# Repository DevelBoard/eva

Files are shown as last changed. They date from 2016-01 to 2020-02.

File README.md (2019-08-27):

# Develer EVA01 Project
Schematics and Gerber for DevelBoard Evaluation, and shield boards.

## EVA01 Releases

### EVA01 Rev.3 (eva01-R3)
 * PCB release Rev.C (pcb-eva01-Rev-C)
 * Move WLAN_PWR singal form PB29 to PE5 pin.
 * Silk screen cosmetic fixes
 
### EVA01 Rev.2 (eva01-R2)
 * PCB release Rev.B (pcb-eva01-Rev-B)
 * Minor fixes
 * Change USB Host connector position
 * Reduce backup battery size
 * Add Bridge diode on Power supply connector
 * Cosmetic fixes
 * Issues:
   * WiFi/BlueTooth enable: Put R10 to NP and R11 to 22R.

### EVA01 Rev.1 (eva01-R1)
 * First Release
 * PCB release Rev.A (pcb-eva01-Rev-A)
 * Issues:
   * J3 Connector Wrong Power Jack polarity -> Inside pin is GND, and output is +24V
 
## Shield Board Releases

### SHIELD Display 7'', CAN, RS232, RS485 Rev.0 (shield_can-display-R0)
* First Release: Automotive shield version. This shield provvide CAN, RS485 and RS232 peripherals, and LCD Display 7'' 800x480 with integrated resisteve touch. The board support the external capacitive touch frame.
 * PCB release Rev.A (pcb-shield_can-display-Rev-A)
 * Issues:
   * J9 Connector mirrored -> the capacitive touch frame not work.
   * Missing pull down on lcd backlight enable

### SHIELD Display 4.3'' Rev.1 (shield_display_4.3-R1)
* First Release: Display shield version. The shield support LCD Display 4.3'' 480x272  with integrated resisteve touch.
 * PCB release Rev.A (pcb-shield_display_4.3-Rev-A)
 * Issues:
   * Missing pull down on lcd backlight enable

### SHIELD IO Rev.0 (shield_io-R0)
 * First release: Generic IO shield this shield provvide 4 Relay SPDT, 2 Digital input Optocoupled, 2 Digital Input, 4 ADC input, 2 ADC Current shunt, 2 Voltage DAC and 2 Current DAC.

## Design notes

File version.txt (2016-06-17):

[eva01]
name=EVA01 Evaluation board for DevelBoard
hw_ver=3
pcb_ver=C
date=20160415

[shield_display_4.3]
name=EVA01 Shield Display 4.3''
hw_ver=2
pcb_ver=C
date=20160616

[shield_can-display]
name=EVA01 Shield Display 7'' with CAN, RS232, RS485
hw_ver=2
pcb_ver=B
date=20160616

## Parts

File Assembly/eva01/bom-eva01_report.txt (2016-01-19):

#     #                             ######
##   ## ###### #####   ####  ###### #     #  ####  #    #
# # # # #      #    # #    # #      #     # #    # ##  ##
#  #  # #####  #    # #      #####  ######  #    # # ## #
#     # #      #####  #  ### #      #     # #    # #    #
#     # #      #   #  #    # #      #     # #    # #    #
#     # ###### #    #  ####  ###### ######   ####  #    #

Report file.
Date: Tue 19 January 2016 10:26:56
Directory: Assembly/eva01
Project Name: EVA01 Evaluation board for DevelBoard
Hardware Revision: 2
PCB Revision: B

Assembly/eva01/bom-eva01.xls
SRC file: Assembly/eva01\tmp_bom-eva01.xls
OUT file: Assembly/eva01\bom-eva01.xls

Check Merged items:
--------------------------------------------------------------------------------
>>  Assembly/eva01\tmp_bom-eva01.xls
>>  Merged key: Mini USB SMT Type B 5 Contacts (WE 65100516121)usb_typeB_mini_smd (Connector)
>>  Merged key: Pin Header, 2pin, 1x2, 2.54mm, THDHEADER_1X2_2.54MM_THD (Connector)
>>  Merged key: CR1612/1616/1620/1632 (3013, Keystone)Battery_holder_16mm_thd (Connector)
>>  Merged key: Pin header 26x2 Stacked > 16mmHEADER_2x26_2.54MM_THD (Connector)
>>  Merged key: Pin header 26x2 Stacked > 16mmHEADER_2x26_2.54MM_THD (Connector)
>>  Merged key: Terminal block Header 3.5mm Horizontal (WE 691322110002)TBLOCK_1X2_3.5MM_HOR_THD (Connector)
>>  Merged key: WR-DC_DC Power Jack_Right Angled_THT (WE  694108301002)DC_Jack_6.5x2.5mm_right_tht (Connector)
!!  Not Populate connector, leave unmerged..[NP (ANT_WLAN_2)] [J15] match[u'NP']
>>  Merged key: SMA, Jack, Right angle, PCB socket, 50ohm (TE 5-1814400-1) NP  (ANT_WLAN_2)SMA_Jack_Female_5.08mm_THD ( NP  (ANT_WLAN_2))
>>  Merged key: WR-CRD Micro SD_Push and Push (693071010811)micro_sd_holder_pp (Connector)
>>  Merged key: Pin header 26x2 Stacked > 16mmHEADER_2x26_2.54MM_THD (Connector)
>>  Merged key: SMA, Jack, Right angle, PCB socket, 50ohm (TE 5-1814400-1)SMA_Jack_Female_5.08mm_THD (Connector)
>>  Merged key: USB Type-A Double Connector (WE  61400826021)USB_TypeA_Double_THD (Connector)
>>  Merged key: Integrated RJ45 Transformer WE-RJ45LAN (WE 74990111217)RJ45_lan_transformer_horizontal (Connector)
>>  Merged key: Pin Header, 4pin, 2x2, 2.54mm, THDHEADER_2X2_2.54MM_THD (Connector)
>>  Merged key: LED Green0603_[1608]_LED (+1.8V)
>>  Merged key: LED Green0603_[1608]_LED (Vusb)
>>  Merged key: LED Green0603_[1608]_LED (+5V)
>>  Merged key: LED Green0603_[1608]_LED (+3.3V)
>>  Merged key: LED Green0603_[1608]_LED (+24V)

================================================================================
 File num: 1

-  C  Capacitors
       C    52
-  D  Diodes
       D     9
-  J  Connectors
       J    14
-  L  Inductors, chokes
       L    21
-  Q  Transistors
       Q     1
-  S  Mechanical parts and buttons
       S     1
-  R  Resistors
       R    75
-  DZ Zener, Schottky, Transil
      DZ     1
-  U  IC
       U    13

~~~~~~~~~~~~~~~~~~~~~~~~~~~~~~~~~~~~~~~~~~~~~~~~~~~~~~~~~~~~~~~~~~~~~~~~~~~~~~~~
>>  Total: 187

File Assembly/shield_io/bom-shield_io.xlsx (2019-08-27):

Bill of Materials
Date: 27/08/2019
Project: Input/Output and Analog expation shield for DevelBoard PN: -
Hardware_version: 0
PCB_version: A
BOM files:
- bom-shield_io.csv
Statistics
NP=NOT POPULATE (NON MONTARE)!
T.Qty | bom-shield_io.csv | Designator | Comment | Footprint | Description
J * Connectors and holders *
4 | 4 | J7, J8, J9, J10 | Connector | TBLOCK_1X2_3.5MM_HOR_THD | Terminal block Header 3.5mm Horizontal (WE 691322110002)
3 | 3 | J12, J13, J14 | Connector | SOCKET_2x26_2.54MM_THD | Socket Header, 52 pin, 26x2, 2.54mm, H=8.5mm
9 | 9 | J1, J2, J3, J4, J5, J6, J11, J15, J16 | Connector | TBLOCK_1X3_3.5MM_HOR_THD | Terminal block Header 3.5mm Horizonta
R * Resistor components *
29 | 29 | R3, R4, R5, R9, R16, R22, R26, R29, R34, R37, R67, R69, R78, R79, R82, R83, R84, R88, R92, R93, R98, R99, R100, R101, R102, R104, R106, R107, R386 | NP | 0603_[1608] | Resistor
2 | 2 | R87, R90 | NP | 0805_[2012] | Resistor
19 | 19 | R1, R7, R8, R10, R14, R19, R25, R28, R33, R36, R57, R58, R85, R89, R94, R95, R103, R105, R387 | 0R | 0603_[1608] | Resistor
4 | 4 | R71, R74, R76, R77 | 22R | 0603_[1608] | Resistor
27 | 27 | R2, R6, R11, R13, R18, R24, R27, R32, R35, R41, R44, R45, R47, R48, R50, R51, R53, R54, R59, R60, R61, R62, R63, R64, R65, R96, R97 | 33R | 0603_[1608] | Resistor
4 | 4 | R30, R31, R38, R39 | 50R mOhm 1% | 1210_[3225] | Resistor
2 | 2 | R86, R91 | 100R 0.1% | 0805_[2012] | Resistor
2 | 2 | R80, R81 | 220R | TRIMMER_THD_5x10MM_HORIZONTAL | Trimmer 23 Turn 220ohm (T93YA221KT20;)
2 | 2 | R70, R75 | 220R | 0603_[1608] | Resistor
5 | 5 | R23, R66, R68, R72, R73 | 1k | 0603_[1608] | Resistor
1 | 1 | R21 | 8k2 1% | 0603_[1608] | Resistor
1 | 1 | R17 | 10k 1% | 0603_[1608] | Resistor
2 | 2 | R12, R15 | 10k | 0603_[1608] | Resistor
1 | 1 | R20 | 47k 1% | 0603_[1608] | Resistor
C * Capacitors *
10 | 10 | C20, C21, C23, C24, C25, C26, C27, C28, C29, C30 | NP | 0603_[1608] | Ceramic X7R 50V
18 | 18 | C2, C4, C5, C7, C8, C9, C11, C12, C13, C14, C15, C16, C17, C18, C19, C22, C31, C104 | 100nF | 0603_[1608] | Ceramic X7R 50V
1 | 1 | C6 | 1uF | 0603_[1608] | Ceramic X5R 25V
3 | 3 | C1, C32, C106 | 10uF | 1206_[3216] | Ceramic X7R 25V
2 | 2 | C3, C10 | 10uF | 0805_[2012] | Ceramic X5R 10V
D * Diodes, Zener, Schottky, LED, Transil *
2 | 2 | DZ1, DZ2 | BZX84-C2V7 | SOT-23 | Zener 2,7V
2 | 2 | D1, D2 | S2B | DO214AA_K1-A2_SMB | S2B Diode
L * L Inductors, chokes *
2 | 2 | L1, L2 | 10uH | 1210_[3225] | INDUCTOR, 1210 CASE, 10.0UH (ELJPA100KF)
Q * Q Transistors, MOSFET *
2 | 2 | Q1, Q2 | FCX690BTA | SOT-89 | NPN Bipolar Transistor
U * Integrates and chips *
1 | 1 | U5 | 24C128 | SOIC8 | EEPROM
1 | 1 | U12 | ACPL-827 | SOIC8_OPTO | Optocoupler
1 | 1 | U44 | AD5624RBRMZ | MSOP50P490X110-10P | 12bit DAC
1 | 1 | U1 | AD7998BRU | TSOP65P640X120-20L | ADC 12bit I2C
2 | 2 | U3, U4 | AD8418BRMZ | MSOP65P490X110-8P | 12bit DAC
2 | 2 | U11, U13 | LM317D | SOT-223 | 3-Terminal Adjustable Regulator, 3-pin SOT-223
1 | 1 | U14 | OPA4188AID | SOIC14 | Quad Op Amp
4 | 4 | U7, U8, U9, U10 | Relay, Rele' | relays_spco_thd_28x12mm_5mm | Rele NT75CS16DC12V0.415.0 16A 12V
1 | 1 | U2 | TLV431 SOT23 | SOT-23 | TLV431BQDBZT
1 | 1 | U6 | ULN2803 | SOIC18 | BJT Darlinton Array

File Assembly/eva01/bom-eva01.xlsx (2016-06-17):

Bill of Materials
Date: Friday, 17 June 2016 12:10:39
Project: EVA01 Evaluation board for DevelBoard
Hardware_version: 3
PCB_version: C
BOM files:
- bom-eva01.xlsx
NP=NON MONTARE!
Statistics:
52 | C Capacitors
9 | D Diodes
14 | J Connectors
21 | L Inductors, chokes
1 | Q Transistors
1 | S Mechanical parts and buttons
75 | R Resistors
1 | DZ Zener, Schottky, Transil
13 | U IC
187 | Total
T.Qty | bom-eva01.xlsx | Designator | Comment | Footprint | Description
J Connectors
1 | 1 | J10 | Connector | HEADER_2X2_2.54MM_THD | Pin Header, 4pin, 2x2, 2.54mm, THD
1 | 1 | J2 | Connector | TBLOCK_1X2_3.5MM_HOR_THD | Terminal block Header 3.5mm Horizontal (WE 691322110002)
3 | 3 | J1, J7, J16 | Connector | HEADER_2x26_2.54MM_THD | Pin header, 2x26, 2.54mm, Stacked H=10mm (LE210280-R)
1 | 1 | J12 | Connector | USB_TypeA_Double_THD | USB Type-A Double Connector (WE 61400826021)
1 | 1 | J4 | Connector | HEADER_1X2_2.54MM_THD | Pin Header, 2pin, 1x2, 2.54mm, THD
1 | 1 | J9 | Connector | usb_typeB_mini_smd | Mini USB SMT Type B 5 Contacts (WE 65100516121)
1 | 1 | J11 | Connector | micro_sd_holder_pp | WR-CRD Micro SD_Push and Push (693071010811)
1 | 1 | J6 | Connector | Battery_holder_16mm_thd | CR1612/1616/1620/1632 (3013, Keystone)
1 | 1 | J3 | Connector | DC_Jack_6.5x2.5mm_right_tht | WR-DC_DC Power Jack_Right Angled_THT (WE 694106301002)
1 | 1 | J14 | Connector | SMA_Jack_Female_5.08mm_THD | SMA, Jack, Right angle, PCB socket, 50ohm (TE 5-1814400-1)
1 | 1 | J13 | Connector | RJ45_lan_transformer_horizontal | Integrated RJ45 Transformer WE-RJ45LAN (WE 74990111217)
1 | 1 | J15 | NP Connector | SMA_Jack_Female_5.08mm_THD | SMA, Jack, Right angle, PCB socket, 50ohm (TE 5-1814400-1)
S Mechanical parts and buttons
1 | 1 | SW1 | RESET | TACTILE_SWITCH_6x6MM_SMD | Tactile switch smd H=4.3mm 10x6mm (like cod. Farnell 2435308)
R Resistors
15 | 15 | R1, R2, R3, R4, R5, R6, R7, R10, R63, R89, R90, R91, R92, R93, R94 | NP | 0603_[1608] | Resistor
1 | 1 | R35 | NP (10k) | 0603_[1608] | Resistor
1 | 1 | R36 | NP (1k) | 0603_[1608] | Resistor
1 | 1 | R87 | 0R | 0603_[1608] | Resistor
26 | 26 | R11, R33, R37, R38, R44, R45, R46, R47, R48, R49, R51, R52, R54, R57, R58, R59, R60, R62, R79, R80, R81, R82, R83, R84, R85, R86 | 22R | 0603_[1608] | Resistor
1 | 1 | R150 | 56R | 0603_[1608] | Resistor
1 | 1 | R17 | 180R | 0603_[1608] | Resistor
3 | 3 | R55, R56, R77 | 470R | 0603_[1608] | Resistor
2 | 2 | R8, R16 | 680R | 0603_[1608] | Resistor
13 | 13 | R9, R14, R15, R39, R50, R53, R70, R72, R73, R74, R75, R76, R78 | 10k | 0603_[1608] | Resistor
5 | 5 | R13, R40, R41, R42, R43 | 68k | 0603_[1608] | Resistor
6 | 6 | R65, R66, R67, R68, R69, R71 | 100k | 0603_[1608] | Resistor
C Capacitors
1 | 1 | C22 | NP (100nF) | 0603_[1608] | Ceramic X7R 50V
2 | 2 | C45, C46 | 100pF | 0603_[1608] | Ceramic COG 50V
2 | 2 | C9, C17 | 10nF | 0603_[1608] | Ceramic X7R 50V
30 | 30 | C2, C3, C6, C11, C14, C15, C18, C19, C20, C21, C23, C25, C27, C28, C30, C31, C32, C33, C34, C35, C36, C37, C38, C39, C43, C44, C47, C48, C73, C74 | 100nF | 0603_[1608] | Ceramic X7R 50V
3 | 3 | C8, C12, C42 | 1uF | 1206_[3216] | Ceramic X7R 50V
1 | 1 | C41 | 4.7uF | 0805_[2012] | Ceramic X7R 10V
1 | 1 | C16 | 4.7uF | 1206_[3216] | Ceramic X5R 25V
10 | 10 | C1, C7, C10, C13, C24, C26, C29, C40, C49, C50 | 10uF | 1206_[3216] | Ceramic X5R 25V
1 | 1 | C4 | 100uF | CAP_6x6_D8_SMD | EEEFK1H101P SMT 6x6 35V
1 | 1 | C5 | 100uF | [7343]_CAP_TAN | Tantalum 10V (T495D107K010ATE100)
D Diodes
1 | 1 | D1 | Bridge Diode | Diode_bridge_smd | MBS4 (Farnell cod:4084985)
5 | 5 | D3, D4, D5, D8, D17 | LED | 0603_[1608]_LED | LED Green
2 | 2 | D6, D7 | MBR120VLSFT1G | SOD-123 | Diode Schottky low Vf, If 1A (PMEG3010ER; MBRX120LF)
1 | 1 | D2 | SMBJ28A | DO214AA_12 | TRANSIL (SM6T12A)
DZ Zener, Schottky, Transil
1 | 1 | DZ1 | B340A | DO214AA_12 | Diode Schottky (STPS2L40U)
L Inductors, chokes
2 | 2 | L10, L11 | Line filter (WE 744232090) | WE-CNSW_1206 | Common mode line filter
1 | 1 | L19 | NP (220 ohm @ 100MHz) | 0805_[2012] | Ferrite Beat (WE 742792022)
1 | 1 | L4 | 10uH WE 74437334100 | WE-LHMI_5020 | SMD Shielded Tiny Power Inductor
3 | 3 | L14, L20, L21 | 180H @ 100Mhz | 0603_[1608] | Ferrite Beat (WE 7427927218)
14 | 14 | L1, L2, L3, L5, L6, L7, L8, L9, L12, L13, L15, L16, L17, L18 | 220H ohm @ 100MHz | 0805_[2012] | Ferrite Beat (WE 742792022)
Q Transistors
1 | 1 | Q1 | NP (IRLML6402) | SOT-23 | Mos N Channel
U IC
1 | 1 | U12 | 32.768kHz Oscillator | CRYSTAL_3.2X1.5MM_4P_SMD | 32.768kHz Oscillator (EPSON X1B0002110001 SG-3030CM)
1 | 1 | U1 | DevelBoard | develboard_footprint | Faster Little Linux Module
1 | 1 | U10 | FPF2124 | SOT-23-5 | Power Load Switch
1 | 1 | U4 | FT232RQ | QFN-32 | Serial TTL 232 <-> USB (QFN-32)
1 | 1 | U3 | LD29150DT33R | TO-252_D2PAK_LARGEPAD | Very Low Drop Linear regulator 3.3V (BA33BC0FP-E2; MIC2940A-3.3WU)
1 | 1 | U28 | LM1117-18 | SOT-223 | LDO, Fixed Vout = 1.8V
1 | 1 | U2 | LM22670MRE-5.0/NOPB | SOIC8_PAD | Power switch
1 | 1 | U5 | SP2526A-1EN-L | SOIC8 | USB Power Supply swtich HI-SIDE dual.
2 | 2 | U6, U7 | TVS Array (WE 82400152) | SOT-563 | TVS Array (WE 82400152)
1 | 1 | U8 | TXB0108PW | TSOP65P640X120-20L | 8-bit bidirectional level translator
1 | 1 | U11 | TXS0108E | TSOP65P640X120-20L | 8-bit bidirectional level translator
1 | 1 | U9 | WL1831MOD | WL18XX_E-13.4X13.3-N100_0.75 | Wifi & Bluethoot module

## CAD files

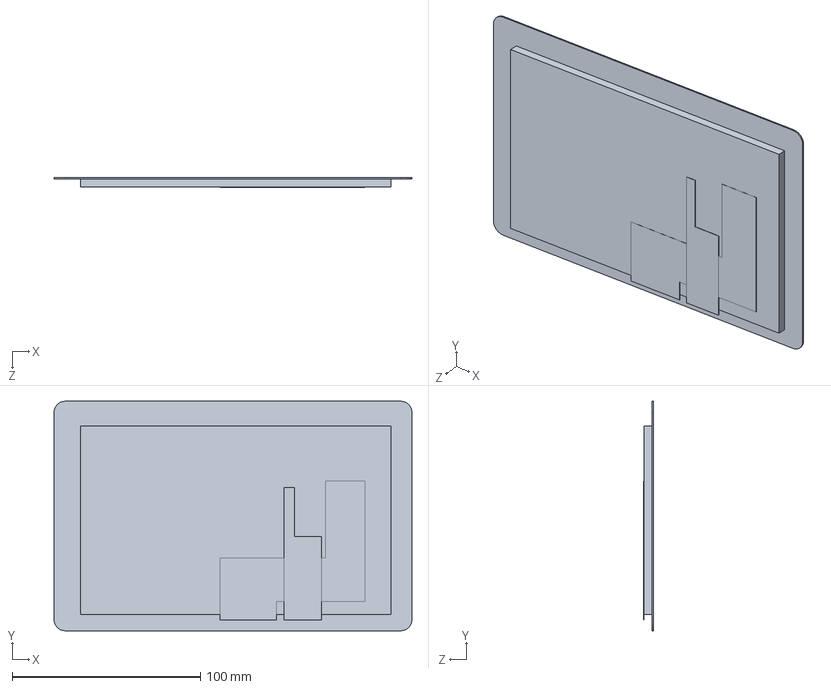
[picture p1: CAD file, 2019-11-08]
Drawing/shield_can-display/display_7.SLDPRT
190.1 x 121.9 x 5.38 mm

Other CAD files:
Drawing/eva01.DWG
Drawing/eva01_outline.dwg

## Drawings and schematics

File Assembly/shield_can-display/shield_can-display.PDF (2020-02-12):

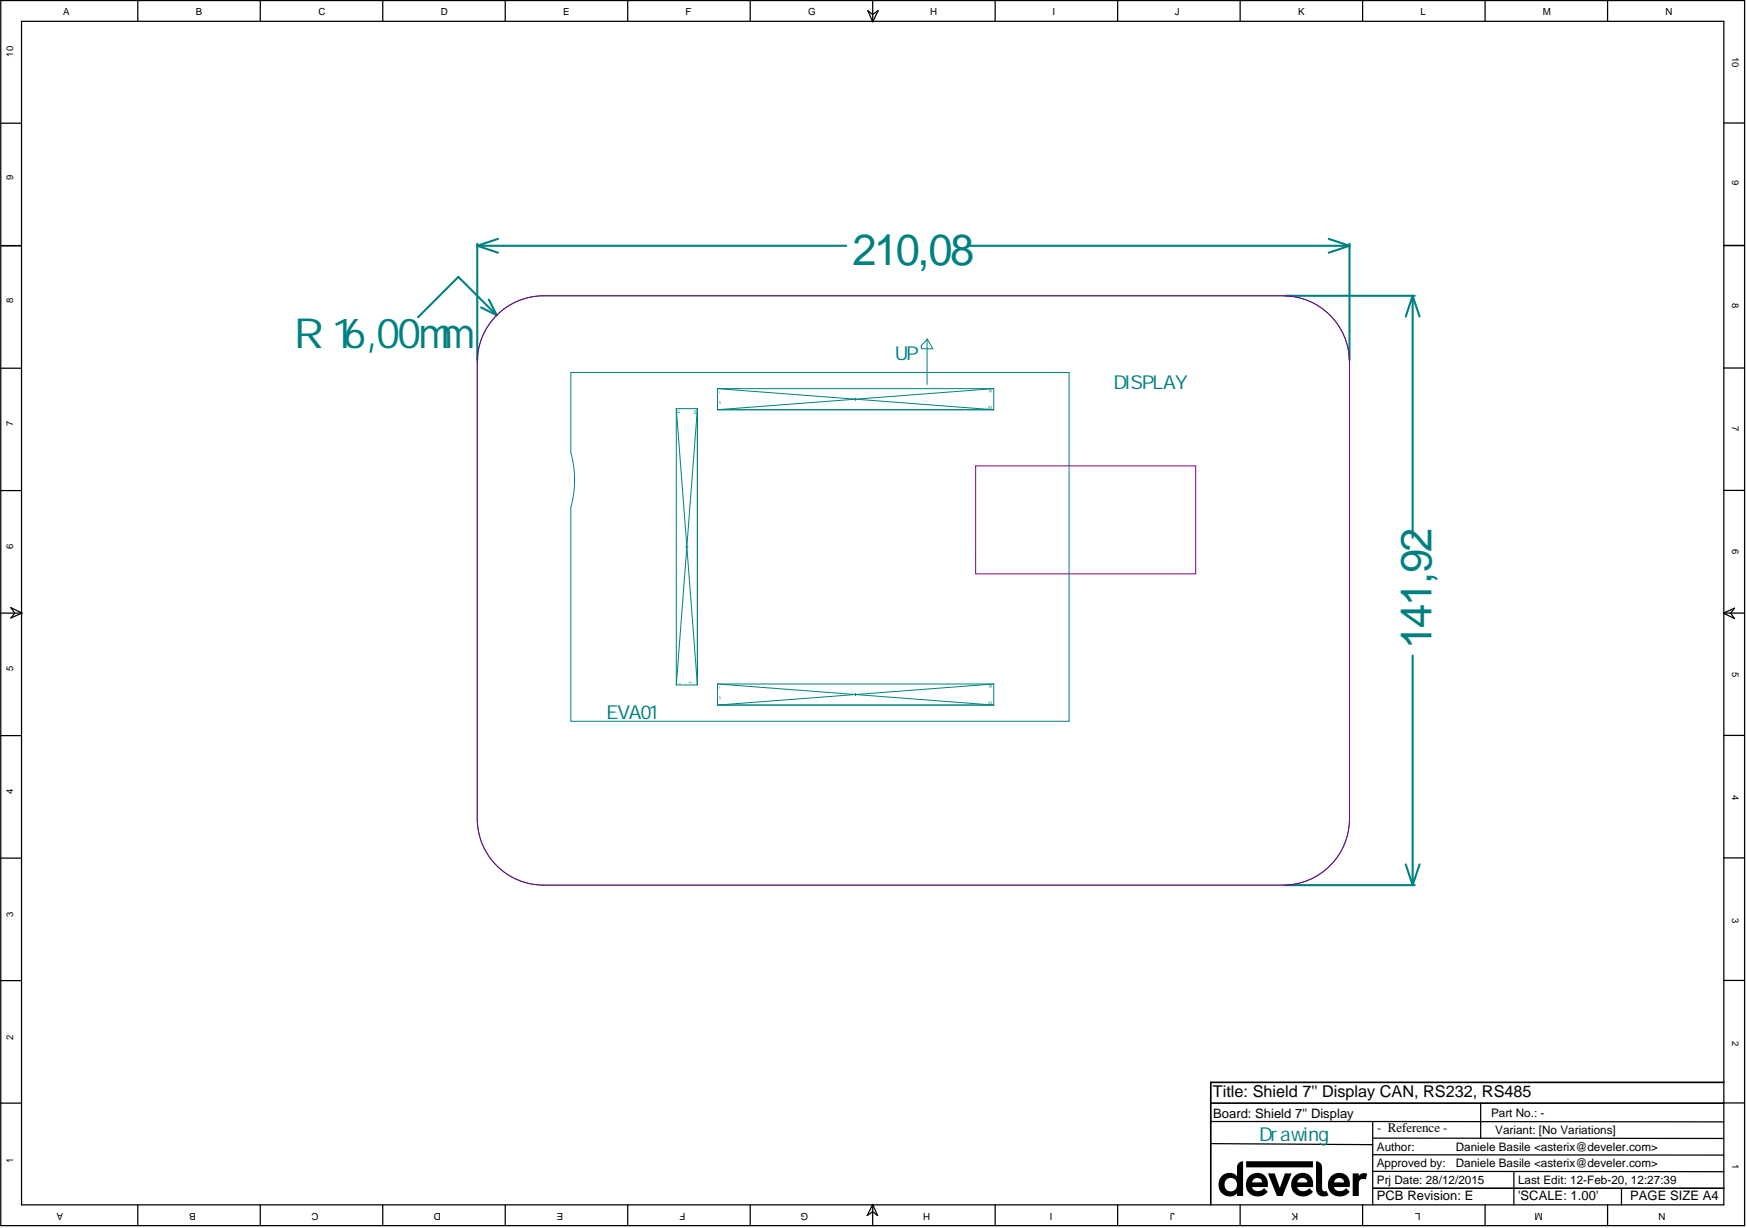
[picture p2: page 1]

Title: Shield 7'' Display CAN, RS232, RS485

Board: Shield 7'' Display | Part No.: -

Dr awing | - Reference - | Variant: [No Variations]

Daniele Basile <asterix@develer.com>

Prj Date: 28/12/2015 | Last Edit: 12-Feb-20, 12:27:39
PCB Revision: E | 'SCALE: 1.00' | PAGE SIZE A4

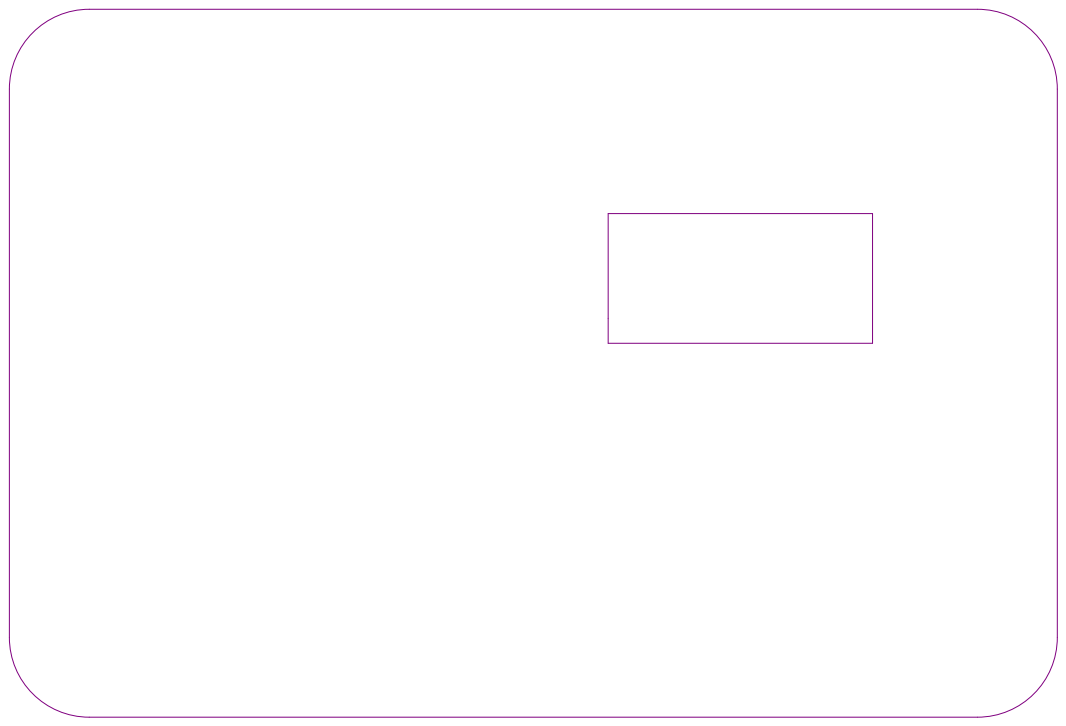
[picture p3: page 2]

Title: Shield 7'' Display CAN, RS232, RS485

Board: Shield 7'' Display | Part No.: -
Top Assembl y

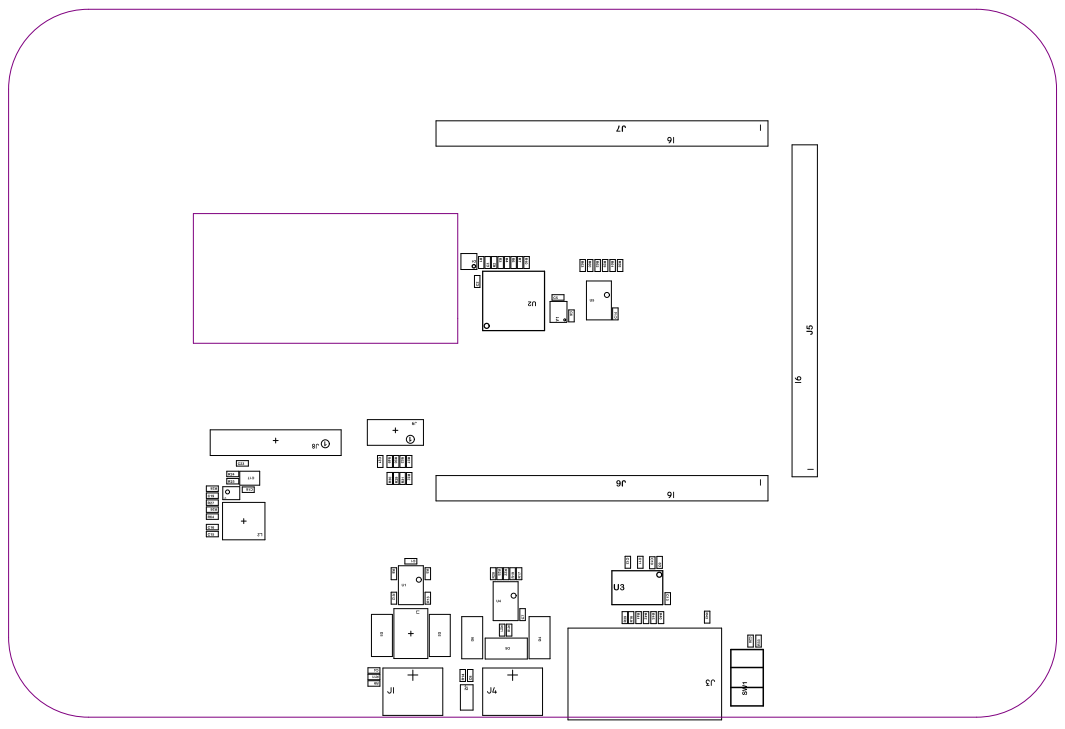
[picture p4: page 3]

Title: Shield 7'' Display CAN, RS232, RS485

Board: Shield 7'' Display | Part No.: -
Top Not e

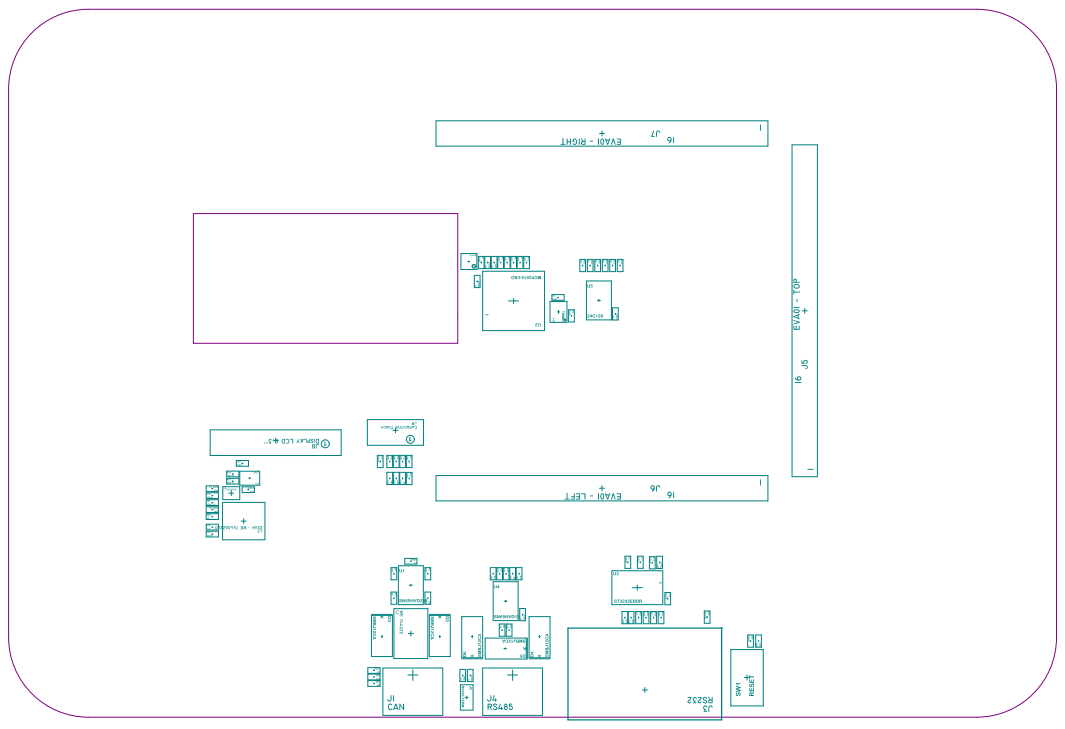
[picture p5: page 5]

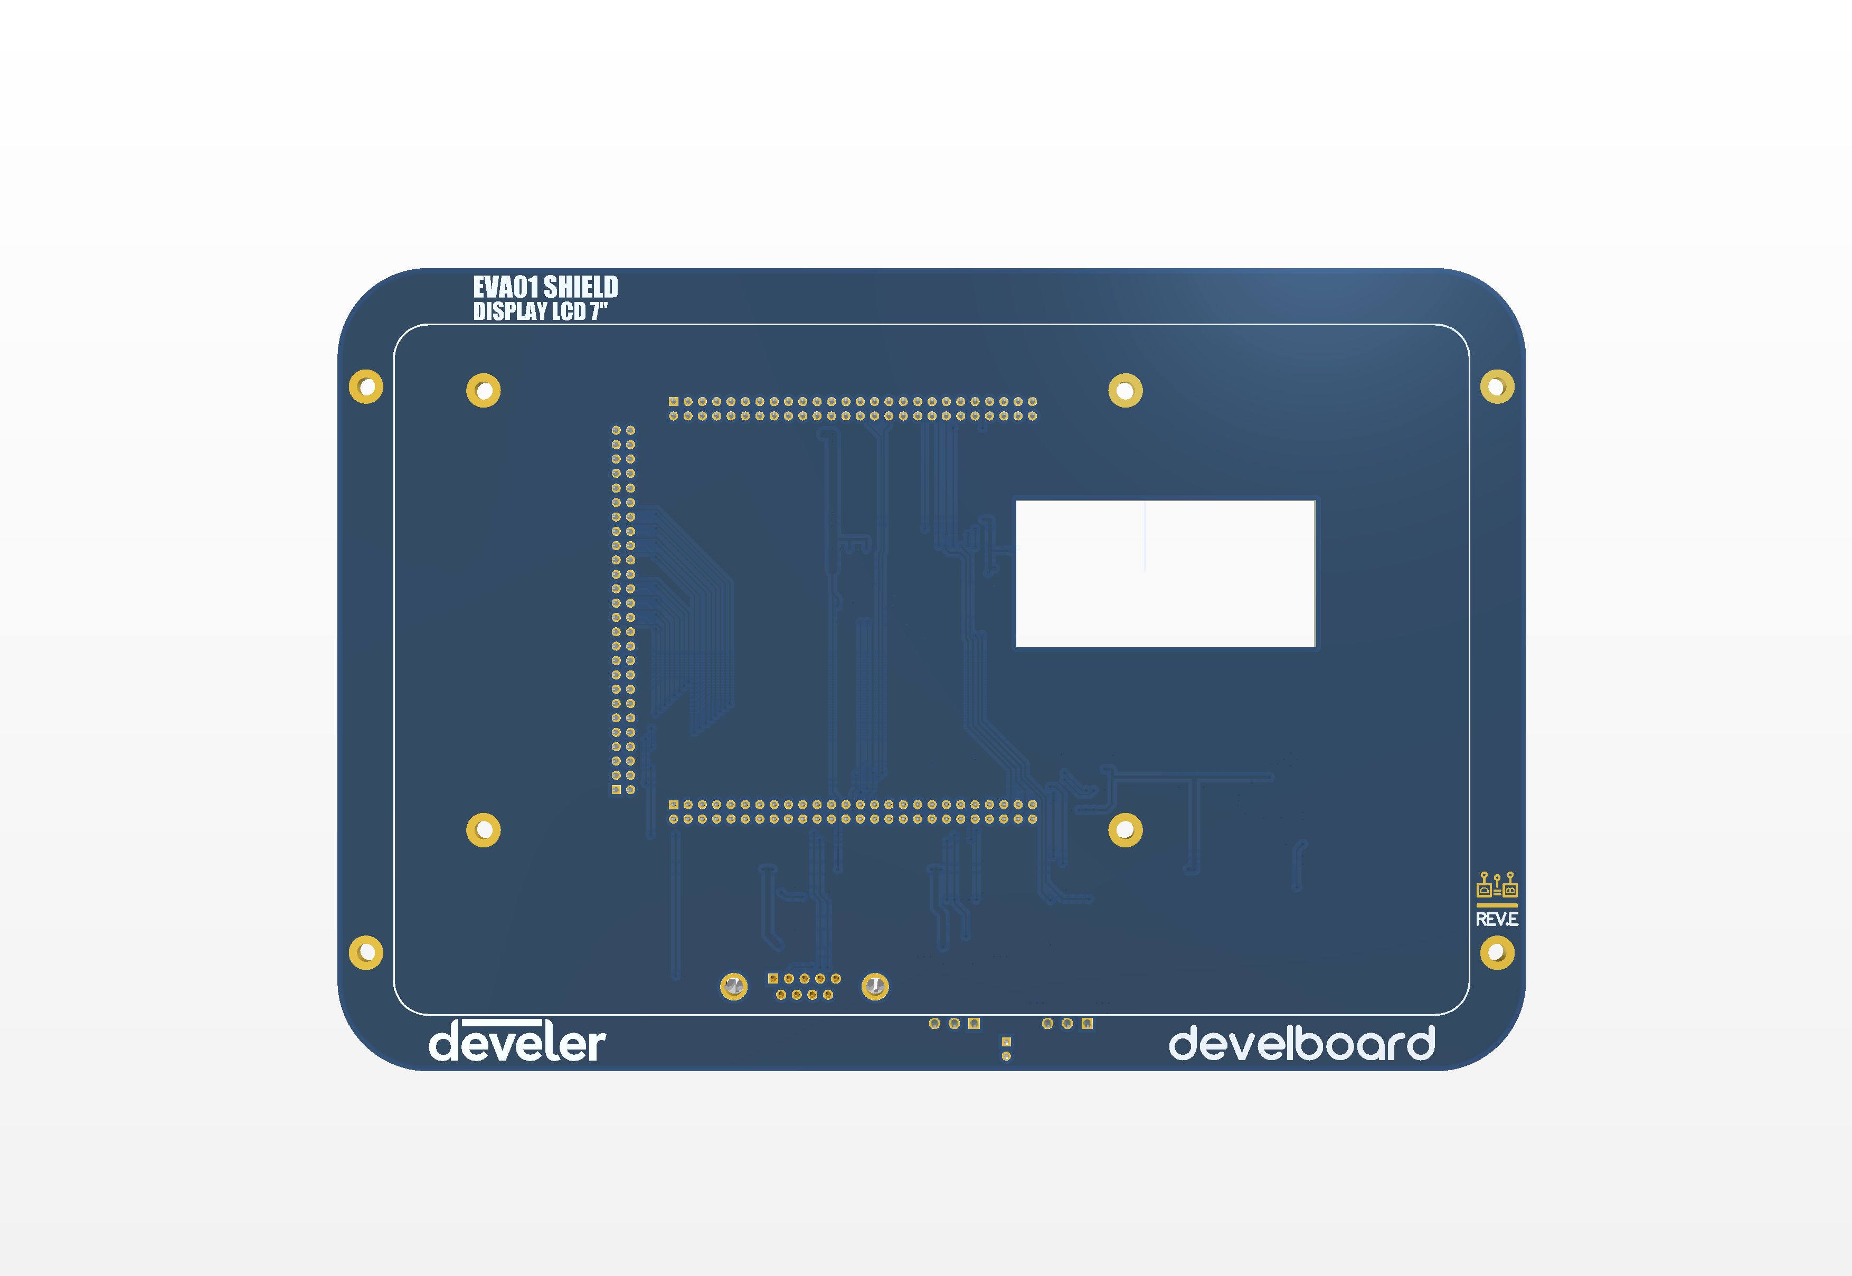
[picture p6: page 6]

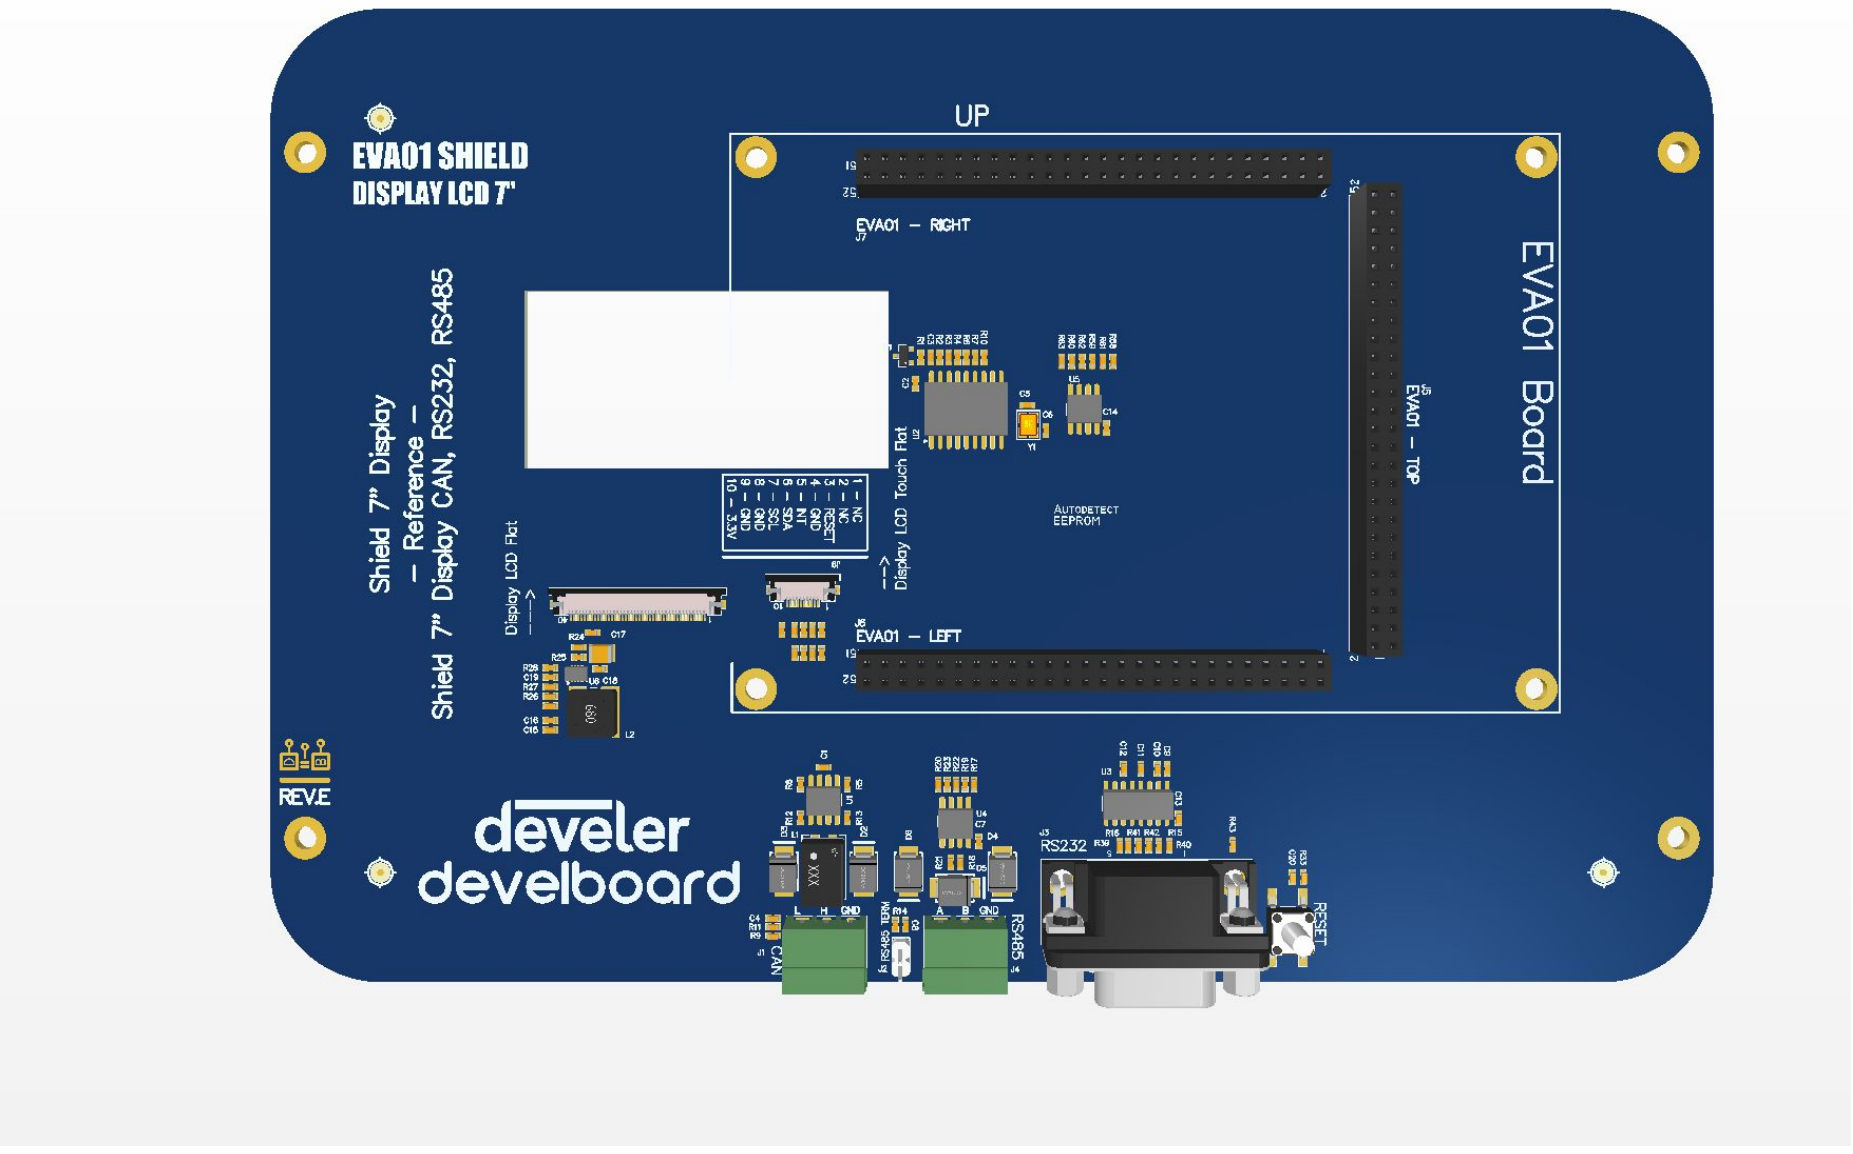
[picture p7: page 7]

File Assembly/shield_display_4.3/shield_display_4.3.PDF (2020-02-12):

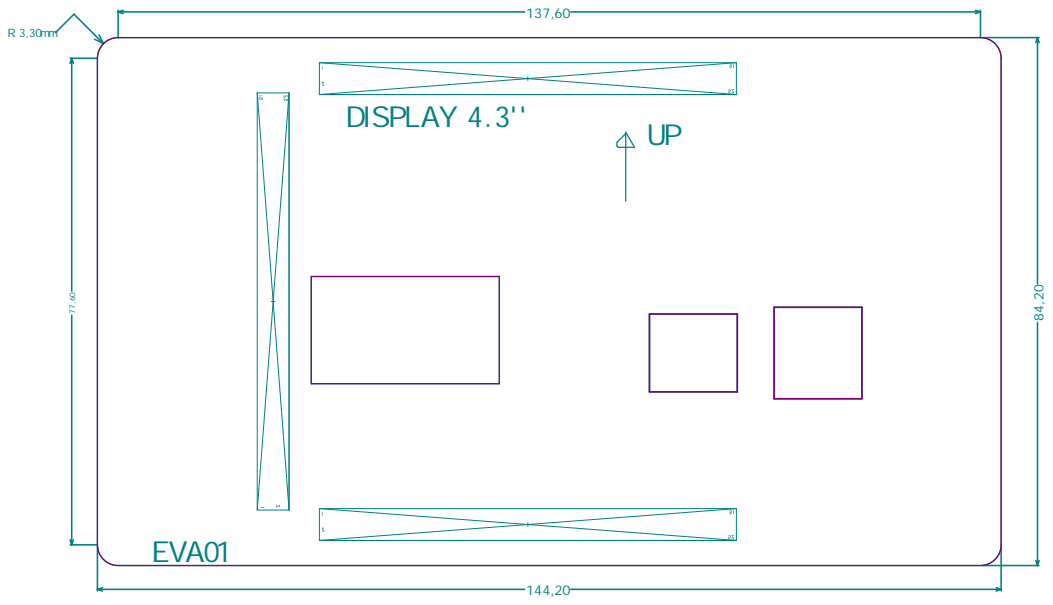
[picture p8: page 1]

Title: Shield 4.3'' Display LCD PCAP

Board: Shield 4.3'' Display | Part No.: -

Dr awing | - Reference - | Variant: [No Variations]

Daniele Basile <asterix@develer.com>

Prj Date: 19/01/2016 | Last Edit: 12-Feb-20, 12:37:16
PCB Revision: D | 'SCALE: 1.00' | PAGE SIZE A4

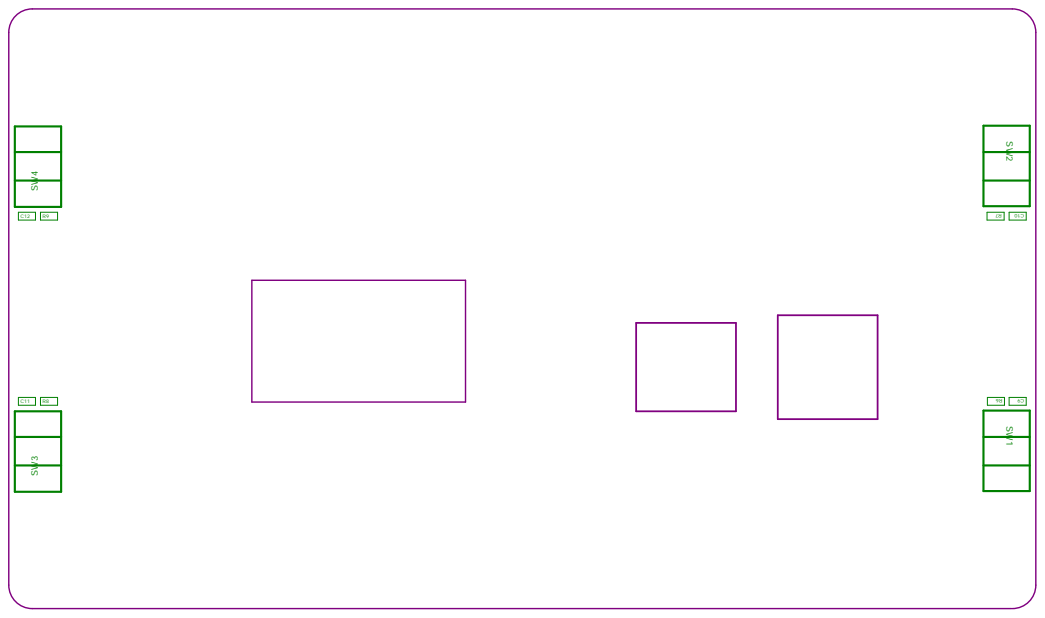
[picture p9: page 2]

Title: Shield 4.3'' Display LCD PCAP

Board: Shield 4.3'' Display | Part No.: -
Top Assembl y

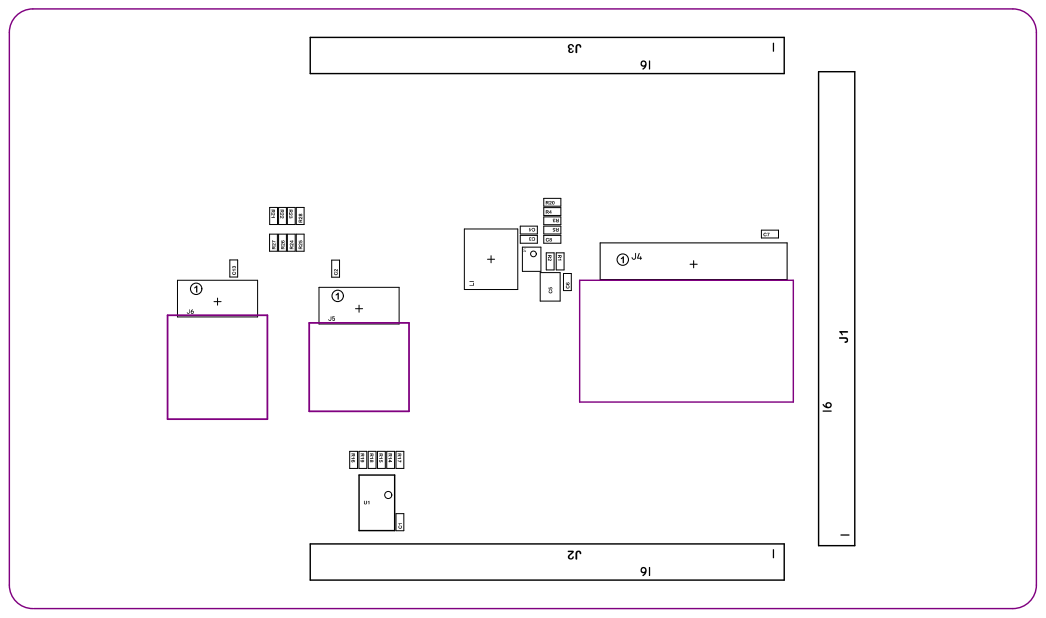
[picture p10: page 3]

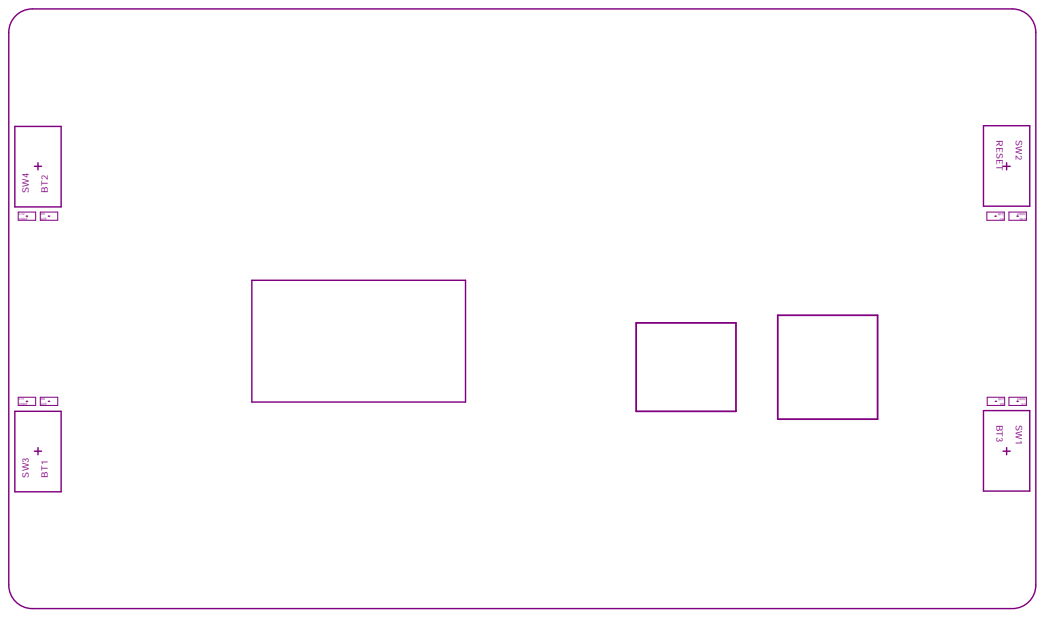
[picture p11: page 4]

Title: Shield 4.3'' Display LCD PCAP

Board: Shield 4.3'' Display | Part No.: -
Top Not e

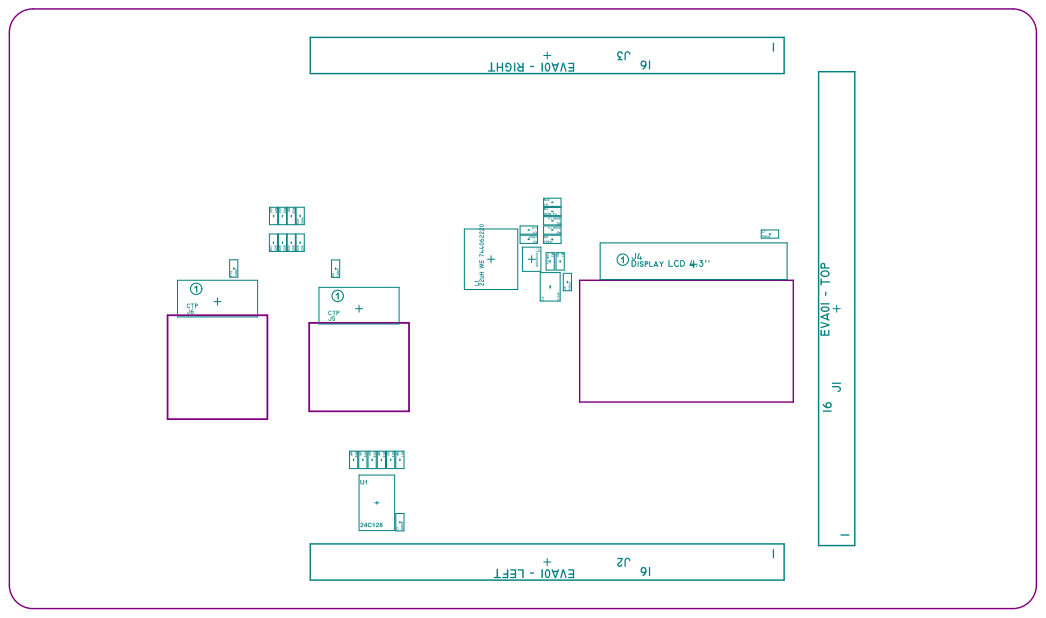
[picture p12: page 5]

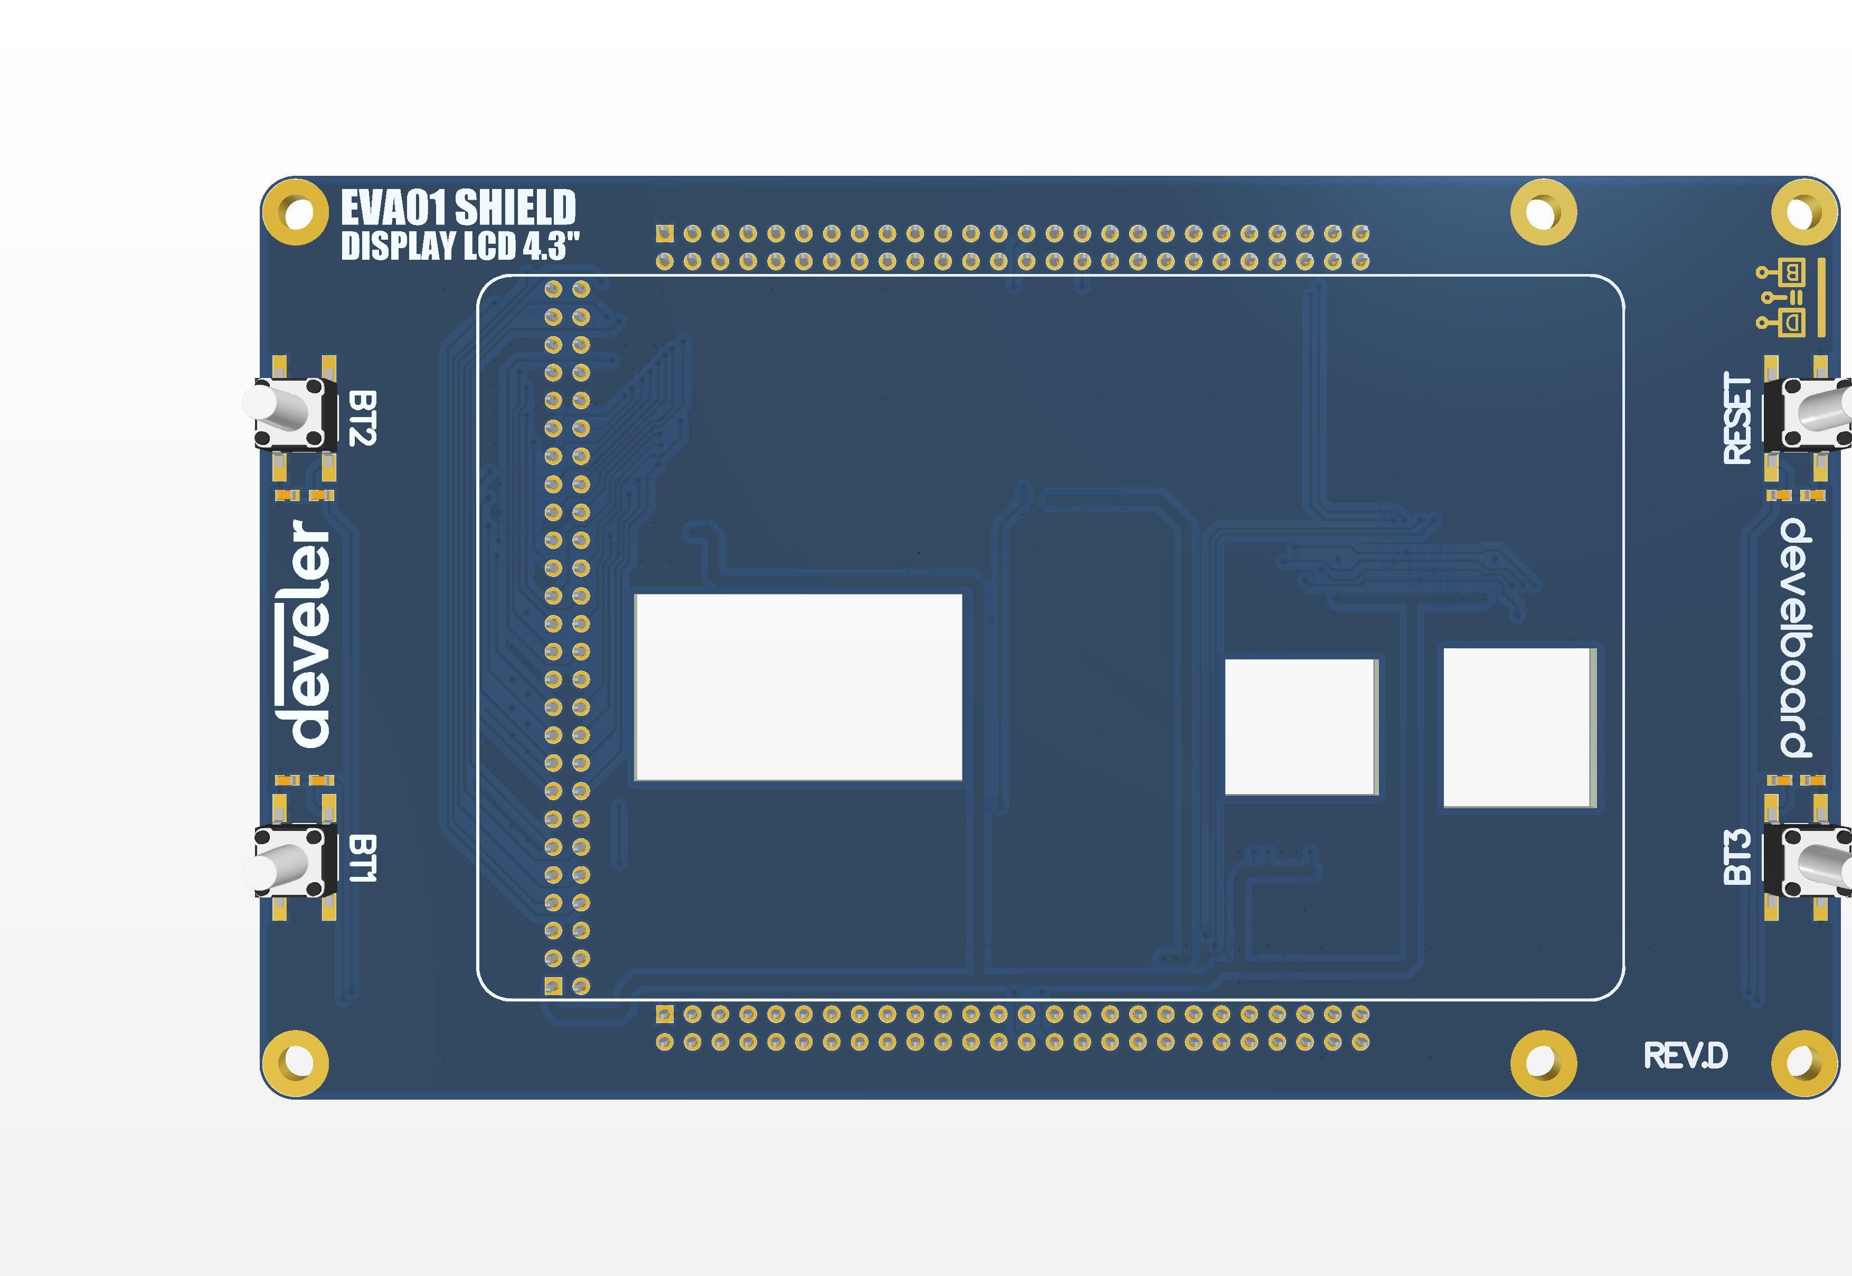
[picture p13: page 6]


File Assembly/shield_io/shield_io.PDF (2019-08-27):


Board Name | IO Shield
P/N | -
Author | Daniele Basile <asterix@develer.com>
Date
Revision | A | A3




U2 TLV431 SOT23 0uF

Tp1 VREF_ADC




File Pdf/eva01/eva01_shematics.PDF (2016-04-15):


Author: Daniele Basile <asterix@develer.com> | Develer s.r.l. via Mugellese 1/A 50019 Campi Bisenzio Firenze ITALY

License: BSD | Hw Rev: R2 | Rev: | Size: A3

Date: 15/04/2016 Time: 15:39:44 | Sheet of



CMD 3 VDD 4 CLK 5 VSS 6 DAT0 7 DAT1 8

DAT2 1

To boot from SD CARD use MCI1A

Title:
DevelBoard EVA01 MicroSD and Debug.



VBUS1

VCC A1

VBUS2

VCC B1

Title:
DevelBoard EVA01 USB Host and Ethernet Connectors.


GND 49 BT_HCI_RTS 50 BT_HCI_CTS 51 BT_HCI_TX 52 BT_HCI_RX 53 GND 54 GND 55 BT_AUD_IN 56 BT_AUD_OUT 57 BT_AUD_FSYNC 58 GND 59 BT_AUD_CLK 60 GND 61 RESERVED3 62 GND 63 RESERVED 64

WL_SDIO_CLK 8 GND 9

WL_SDIO_D0 10 WL_SDIO_D1 11 WL_SDIO_D2 12 WL_SDIO_D3 13 WLAN_IRQ 14 GND 15 | C42



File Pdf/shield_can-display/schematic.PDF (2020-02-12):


Pin numbers are inverted wrt
datasheet because the pin
numbering on the molex
connector is inverted as well!

39
38
37

PA16_LCDDAT16_NTRST_H6 | | | 36
PA17_LCDDAT17_D4 | | | 35

PA18_LCDDAT18_G1_RX2_G4 | | | 33

PA20_LCDDAT20_G1_TX2_A3 | 32

PA21_LCDDAT21_G1_TX3_B4 | 30
PA22_LCDDAT22_G1_MDC_B3 | 29

PA8_LCDDAT8_TCK_A5 | 28

PA9_LCDDAT9_G1_COL_F4 | 26

PA11_LCDDAT11_G1_RXER_D5 | 25

PA12_LCDDAT12_G1_RX0_G5 | 23
PA13_LCDDAT13_G1_RX1_C5 | 22

PA15_LCDDAT15_G1_TX1_B5 | 21

PA0_LCDDAT0_TMS_A7 | 19

PA2_LCDDAT2_G1_TXCK_E6 | 18
PA3_LCDDAT3_G1_RXCK_C6 | 17

PA4_LCDDAT4_G1_TXEN_D6 | 15

7'' LCD display with PCAP Title:

Project:
License:
Daniele Basile <asterix@develer.com> Author:


PA27_LCDHSYNC_PWML0_SPI1_NPCS2_H4 | PA29_LCDDEN_PWML1_J5
PA26_LCDVSYNC_PWMH0_SP1_NPCS1_E3 | PA24_LCDPWM_PCK0_H5
PA28_LCDPCK_PWMH1_SP1_NPCS3_G3 | PA25_LCDDISP_TD0_F3

PA23_LCDDAT23_G1_MDIO_A4 | PA22_LCDDAT22_G1_MDC_B3
PA21_LCDDAT21_G1_TX3_B4 | PA20_LCDDAT20_G1_TX2_A3
PA19_LCDDAT19_G1_RX3_C4 | PA18_LCDDAT18_G1_RX2_G4
PA17_LCDDAT17_D4 | PA16_LCDDAT16_NTRST_H6

PA13_LCDDAT13_G1_RX1_C5 | PA12_LCDDAT12_G1_RX0_G5
PA11_LCDDAT11_G1_RXER_D5 | PA10_LCDDAT10_G1_RXDV_F5
PA9_LCDDAT9_G1_COL_F4 | PA8_LCDDAT8_TCK_A5

PA7_LCDDAT7_E5 | PA6_LCDDAT6_G1_CRS_A6
PA5_LCDDAT5_G1_TXER_B6 | PA4_LCDDAT4_G1_TXEN_D6
PA3_LCDDAT3_G1_RXCK_C6 | PA2_LCDDAT2_G1_TXCK_E6
PA1_LCDDAT1_F6 | PA0_LCDDAT0_TMS_A7

PC28_AD1_SPI0_NPCS2_PWML1_T11 | PB19_SPI1_MOSI_C1
PC29_AD2_SPI0_NPCS3_PWMFI0_R13 | PB20_SPI1_SPCK__D1
PC30_AD3_PWMH0_T12 | PB23_SPI1_NPCS2_H1

PC0_SPI0_MISO_PWMH2_ISI_D8 | PD31_SPI0_NPCS2_PCK1_P5

BOOT_RECOVERY | PIOBU1

DevelBoard EVAMain Connectors Title:

Daniele Basile <asterix@develer.com> Author:


PD11_RTS0_SPI2_MISO_N3 | D 4

Francesco Sacchi <batt@develer.com> Author:



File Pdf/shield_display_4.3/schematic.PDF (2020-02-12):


PA27_LCDHSYNC_PWML0_SPI1_NPCS2_H4 | PA29_LCDDEN_PWML1_J5
PA26_LCDVSYNC_PWMH0_SP1_NPCS1_E3 | PA24_LCDPWM_PCK0_H5
PA28_LCDPCK_PWMH1_SP1_NPCS3_G3 | PA25_LCDDISP_TD0_F3

PA23_LCDDAT23_G1_MDIO_A4 | PA22_LCDDAT22_G1_MDC_B3
PA21_LCDDAT21_G1_TX3_B4 | PA20_LCDDAT20_G1_TX2_A3
PA19_LCDDAT19_G1_RX3_C4 | PA18_LCDDAT18_G1_RX2_G4
PA17_LCDDAT17_D4 | PA16_LCDDAT16_NTRST_H6

PA13_LCDDAT13_G1_RX1_C5 | PA12_LCDDAT12_G1_RX0_G5
PA11_LCDDAT11_G1_RXER_D5 | PA10_LCDDAT10_G1_RXDV_F5
PA9_LCDDAT9_G1_COL_F4 | PA8_LCDDAT8_TCK_A5

PA7_LCDDAT7_E5 | PA6_LCDDAT6_G1_CRS_A6
PA5_LCDDAT5_G1_TXER_B6 | PA4_LCDDAT4_G1_TXEN_D6
PA3_LCDDAT3_G1_RXCK_C6 | PA2_LCDDAT2_G1_TXCK_E6
PA1_LCDDAT1_F6 | PA0_LCDDAT0_TMS_A7

PC28_AD1_SPI0_NPCS2_PWML1_T11 | PB19_SPI1_MOSI_C1
PC29_AD2_SPI0_NPCS3_PWMFI0_R13 | PB20_SPI1_SPCK__D1
PC30_AD3_PWMH0_T12 | PB23_SPI1_NPCS2_H1

PC0_SPI0_MISO_PWMH2_ISI_D8 | PD31_SPI0_NPCS2_PCK1_P5

BOOT_RECOVERY | PIOBU1


39
38
37
36

PA18_LCDDAT18_G1_RX2_G4 | 34

PA19_LCDDAT19_G1_RX3_C4 | 32

LCD Display:
TFT 4.3" RGB 480*272 IPS and PCAP

PA21_LCDDAT21_G1_TX3_B4 | 31

PA22_LCDDAT22_G1_MDC_B3 | 29
PA23_LCDDAT23_G1_MDIO_A4 | 28

PA9_LCDDAT9_G1_COL_F4 | 27

PA10_LCDDAT10_G1_RXDV_F5 | 25

PA12_LCDDAT12_G1_RX0_G5 | 24
PA13_LCDDAT13_G1_RX1_C5 | 23

PA14_LCDDAT14_G1_TX0_E4 | 21

PA0_LCDDAT0_TMS_A7 | 20

PA1_LCDDAT1_F6 | 18

PA3_LCDDAT3_G1_RXCK_C6 | 17
PA4_LCDDAT4_G1_TXEN_D6 | 16

PA5_LCDDAT5_G1_TXER_B6 | 14

PA7_LCDDAT7_E5 | 13

12
11

PA28_LCDPCK_PWMH1_SP1_NPCS3_G3 | 10

PA27_LCDHSYNC_PWML0_SPI1_NPCS2_H4 | 9

PA26_LCDVSYNC_PWMH0_SP1_NPCS1_E3 | 7



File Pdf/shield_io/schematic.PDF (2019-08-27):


Terminal Block connectors Title:

Project:
License:
Daniele Basile <asterix@develer.com> Author:


PA13_LCDDAT13_G1_RX1_C5 | PA12_LCDDAT12_G1_RX0_G5
PA11_LCDDAT11_G1_RXER_D5 | PA10_LCDDAT10_G1_RXDV_F5
PA9_LCDDAT9_G1_COL_F4 | PA8_LCDDAT8_TCK_A5

PA5_LCDDAT5_G1_TXER_B6 | PA4_LCDDAT4_G1_TXEN_D6
PA3_LCDDAT3_G1_RXCK_C6 | PA2_LCDDAT2_G1_TXCK_E6
PA1_LCDDAT1_F6 | PA0_LCDDAT0_TMS_A7

PC27_AD0_SPI0_NPCS1_PWML0_U12 | PB18_SPI1_MISO_K2
PC28_AD1_SPI0_NPCS2_PWML1_T11 | PB19_SPI1_MOSI_C1
PC29_AD2_SPI0_NPCS3_PWMFI0_R13 | PB20_SPI1_SPCK__D1
PC30_AD3_PWMH0_T12 | PB23_SPI1_NPCS2_H1

PB3_G0_TXER_CTS2_ISI_VSYNC_C2 | PB14_G0_TX2_SPI2_NPCS1_PWMH0_A1
PB24_DRXD_TDI_E1 | PB15_G0_TX3_SPI2_NPCS2_PWML0_E2
PB10_G0_RX2_PCK2_PWML1_F1 | PB22_SPI1_NPCS1_G1
PB5_G0_COL_TXD2_PCK2_H2 | PB25_DTXD_TDO_J1
PB4_G0_CRS_RXD2_ISI_HSYNC_J3 | PB11_G0_RX3_RTS2_PWMH1_K4
PB28_SPI2_NPCS3_TD0_PWMH1_K1 | PB21_SPI1_NPCS0_L3
PB31_TF0_L1 | PB27_SPI1_NPCS3_TK0_PWML0_L2
PD8_PCK0_M1 | PD9_FIQ_M2
PD12_RXD0_N1 | PE31_ADTRG_L4
PD11_RTS0_SPI2_MISO_N3 | PD10_CTS0_N2
PD29_SCK1_P1 | PD13_TXD0_SPI2_MOSI_P3
PE29_DIBP_URXD0_TWD1_V1 | PD28_SCK0_R1
PE30_DIBN_UTXD0_TWCK1_U2 | SHDN_T2
PD16_RXD1_R2 | PD17_TXD1_SPI2_NPCS0_R3

PE15_SCK3_TIOA0_N18 | PE17_TXD3_TCLK0_N19
PE25_SCK4_IRQ_M17 | PE11_TCLK2_R18
PE24_RTS3_L19 | PE13_TIOB1_PWML2_P18
PE7_TIOB3_PWMFI1_U19 | PE9_TIOA2_T18
PE14_TCLK1_PWMH3_N17 | PE6_TIOA3_V19
PC25_ISI_D6_TWD3_URXD1_V17 | PE12_TIOA1_PWMH2_P17
PE5_CTS3_R17 | PE27_TXD4_M16
PE1_MCI0_DB0_U17 | PE2_MCI0_DB1_T17
PE3_MCI0_DB2_P16 | PE4_MCI0_DB3_U18
PE8_TCLK3_PWML3_T19 | PE26_RXD4_L15
PE16_RXD3_TIOB0_M15 | PC26_ISI_D7_TWCK3_UTXD1_R16
PC23_ISI_D4_RD1_U16 | PC21_ISI_D2_TD1_U15
PC24_ISI_D5_RK1_PCK1_T16 | PE0_MCI0_CDB_CTS4_W19
PC19_ISI_D0_TK1_U14 | PC31_AD4_PWMH1_T13
PD25_R11 | PC4_SPI0_NPCS1_MCI0_CK_PCK1_W5
PC20_ISI_D1_TF1_V11 | PD19_P11
PD22_U11 | PD24_U10

PD27_T14 | PB26_PCK0_RK0_PWMH0_M5
PD20_T10 | PD15_RTS1_SPI2_SPCK_N4

DevelBoard EVA Main Connectors Title:


NO2 | NO_OUT0

NC2 | NC_OUT3

NO2 | NO_OUT3

Relays and digital input Title:


CUR0_CON+ | 3 | C UR0


IR DAC Voltage generator

CUR_DAC_Va | VoutB 2











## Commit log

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2015-10-26 Clean up and order scheme names.
    [carrier.PrjPcb, cgd_rif.schdoc, connector_and_other.SchDoc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]
2015-10-26 Place correct labels and connect theirs to various part.
    [connectors.SchDoc, develboard.SchDoc, sd_debug.SchDoc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]
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2015-10-26 Re annotate all scheme. Fist component placing. Add socket drawing.
    [carrier.PrjPcb, connectors.SchDoc, develboard.SchDoc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]
2015-10-26 Define board shape and place the develboard.
    [connectors.SchDoc, develboard.SchDoc, sd_debug.SchDoc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]
2015-10-26 Connect all signals to pin headers.
    [connectors.SchDoc, develboard.SchDoc, sd_debug.SchDoc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]
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2015-10-26 Route double usb host.
    [usb_ethernet.SchDoc]
2015-10-26 Place and route +5V switch power.
    [develboard.SchDoc, supply.SchDoc, wifi.schdoc]
2015-10-26 Some fix, place and route ethernet connector and usb serial debugger.
    [connectors.SchDoc, sd_debug.SchDoc, supply.SchDoc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]
2015-10-26 Start to route display connector.
    [connectors.SchDoc]
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2015-10-26 Minor fixes.
    [usb_ethernet.SchDoc]
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2015-10-26 Add gerbers and output files.
    [develboard_sdk.GBL, develboard_sdk.GBO, develboard_sdk.GBP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]
2015-10-26 Some fix to sst, and regenerate output files.
    [connectors.SchDoc, develboard.SchDoc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]
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2015-10-26 Fix names.
    [bom-develboard-sdk.xls, develboard-sdk.PrjPcb, sd_debug.SchDoc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]
2015-10-26 Rename whole project in eva.
    [bom-develboard-eva.xls, develboard-eva.PrjPcb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]
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2015-12-28 Add 7" LCD shield schematics
    [can.SchDoc, eva01_connectors.SchDoc, lcd.SchDoc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]
2015-12-28 Add 4.3" LCD shield
    [eva01_connectors.SchDoc, lcd.SchDoc, shield_lcd4.3.PrjPcb]
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2015-12-28 Fix lcd connector pin numbering.
    [lcd.SchDoc]
2015-12-29 Assign all footprint to compoment. Add pcb file.
    [can.SchDoc, eva01_connectors.SchDoc, lcd.SchDoc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]
2015-12-30 Annotate schematics; add footprints; reformat.
    [eva01_connectors.SchDoc, lcd.SchDoc, shield_lcd4.3.PrjPcb]
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2015-12-30 First placing and some fixes.
    [can.SchDoc, eva01_connectors.SchDoc, lcd.SchDoc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]
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2015-12-31 Route display connector and equalize nets.
    [eva01_connectors.SchDoc, shield_can-display.PcbDoc]
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2016-01-01 Place all route. Add planes.
    [lcd.SchDoc, shield_can-display.PcbDoc]
2016-01-04 Place silkscreen and logos.
    [lcd.SchDoc, shield_can-display.PcbDoc]
2016-01-04 Fix silkscreen. Place holes. Other fixes.
    [can.SchDoc, eva01_connectors.SchDoc, lcd.SchDoc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]
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2016-01-04 Fix flat connector position.
    [bom-shield_can-display.xls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]
2016-01-05 Update xls sheet with formula to equalize lcd bus. Other fixes.
    [connectors.SchDoc, develboard.SchDoc, sdio_net_eq.xlsx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]
2016-01-05 Start wifi and bluetooth enable pins separation.
    [wifi.schdoc]
2016-01-07 Fix WiFi/BT pins.
    WLAN_PWR -> from PC27 to PB29
    WLAN_EN -> from PC28 to PD26
    Add BT_EN -> PB30
    [wifi.schdoc]
2016-01-07 Add pull-up on USB_OVCUR pin.
    [usb_ethernet.SchDoc]
2016-01-07 Add jumpers on USB and +24V +5B power rails.
    [sd_debug.SchDoc, supply.SchDoc]
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2016-01-07 Move jumper to +24V rail.
    [supply.SchDoc]
2016-01-08 Fix display routing.
    [bom-shield_can-display.xls, lcd.SchDoc, sdio_net_eq.xlsx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]
2016-01-08 Route and define pcb board of lcd 4.3''. Add output files.
    [eva01_connectors.SchDoc, lcd.SchDoc, shield_lcd4-3.PcbDoc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]
2016-01-11 Complete routing. Place power plane.
    [eva01_connectors.SchDoc, lcd.SchDoc, shield_lcd4-3.PcbDoc]
2016-01-11 Fix silk screen.
    [shield_can-display.PcbDoc, shield_can-display.PrjPcb]
2016-01-11 Fix board name.
    [connectors.SchDoc, develboard.SchDoc, sd_debug.SchDoc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]
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2016-01-11 Add pcb prj for display pannel.
    [PCB_Project.PrjPcb, display_shield_pannel.PcbDoc]
2016-01-11 Generate gerber for pannel. Add project and all needed files.
    [display_shield_pannel.GBL, display_shield_pannel.GBO, display_shield_pannel.GBP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]
2016-01-11 Add fiducial and quote for internal slots.
    [shield_can-display.PcbDoc, shield_lcd4-3.PcbDoc]
2016-01-11 Some fixes.
    [display_shield_pannel.GBL, display_shield_pannel.GBO, display_shield_pannel.GBP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]
2016-01-11 More info in pannel pcb note.
    [display_shield_pannel.PcbDoc, shield_can-display.PcbDoc]
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2016-01-11 Add output files. Clean up, and update.
    [bom-eva01.xls, bom-shield_can-display.xls, bom-shield_lcd4.3.xlsx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]
2016-01-11 Assign missing footprint.
    [connectors.SchDoc, sd_debug.SchDoc, supply.SchDoc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]
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2016-01-11 Start to fix eva01 board.
    [eva01.PrjPcb, supply.SchDoc]
2016-01-12 Continue fixing.
    [connectors.SchDoc, supply.SchDoc, wifi.schdoc]
2016-01-14 Complete routing. Fix rules for all diff pair.
    [supply.SchDoc, usb_ethernet.SchDoc]
2016-01-14 Start to fix power planes.
    [supply.SchDoc]
2016-01-15 Complete route fixing. Fix errors.
    [connectors.SchDoc, eva01.PrjPcb, usb_ethernet.SchDoc]
2016-01-18 Complete routing and fixes. Generate gerber and output files.
    [bom-eva01.xls, bom-eva01.xlsx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]
2016-01-18 Minor fix, update gerbers.
    [eva01.GBL, eva01.GBO, eva01.GBP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]
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2016-01-19 Update bom and settings.
    [bom-eva01.xlsx, wifi.schdoc]
2016-01-19 Reorder shield 4.3'' display directory prj.
    [bom-shield_display_4.3.xlsx, bom-shield_lcd4.3.xlsx, display.SchDoc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]
2016-01-19 Update shield can display.
    [bom-shield_can-display.xls, bom-shield_can-display.xlsx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]
2016-01-19 Update shield display 4.3.
    [bom-shield_display_4.3.xlsx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]
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2016-01-19 Add more note to pcb. Fix mirrored test on bottom side.
    [eva01.GBL, eva01.GBO, eva01.GBP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]
2016-02-09 Update version in schematics. Update all output files.
    [bom-eva01.xlsx, connectors.SchDoc, develboard.SchDoc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]
2016-02-16 Add more quotes for eva01 shield connectors.
    [eva01.PrjPcb]
2016-04-15 Some cosmetics fix on silkscreen.
    [bom-eva01.xlsx, display_shield_pannel.PcbDoc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]
2016-04-15 Move wlan_power to pe5.
    [display_shield_pannel.PrjPcb, shield_can-display.PrjPcb, shield_display_4.3.PrjPcb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]
2016-04-15 Bump up version and update output files.
    [bom-eva01.xlsx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]
2016-04-15 Fix eeprom address. Add pull up on backlight supply. Make more wide display flat hole. Minor fix on silk screen.
    [shield_display_4.3.PrjPcb]
2016-04-15 Some bom fix. Update all output files.
    [bom-shield_display_4.3.xlsx, display.SchDoc, eva01_connectors.SchDoc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]
2016-06-16 Add support for display 4.3'' with capacitive touch.
    [display.SchDoc, shield_display_4.3.PrjPcb]
2016-06-16 Fix connector pin out for touch frame. Add pull-down resistor on back light power supply. Add connector for new 7'' lcd display with integrated touch. Minor fixes.
    [can.SchDoc, eva01_connectors.SchDoc, lcd.SchDoc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]
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2016-06-16 Generate gerber for pannels.
    [display_shield_pannel.GBL, display_shield_pannel.GBO, display_shield_pannel.GBP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]
2016-06-16 Use hatch for polygons. Add pcb note info.
    [display_shield_pannel.PcbDoc]
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2016-06-17 Update and clean up.
    [bom-eva01.xlsx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]
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2019-08-25 Remove missing file from projects.
    [eva01.PrjPcb, shield_display_4.3.PrjPcb]
2019-08-25 shield: add first skell of generic i/o shield.
    [eva01_connectors.SchDoc, io_shield.PcbDoc, io_shield.PrjPcb]
2019-08-25 shield: add dac. Start routing.
    [adc.SchDoc, connectors.SchDoc, dac.SchDoc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]
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2019-08-26 shield: Comesmetic fix. Add silkscreen. Run desing rule checker.
    [connectors.SchDoc, eva01_connectors.SchDoc, io_shield.PrjPcb]
2019-08-27 shield: generate output files. Clean up project and give correct name.
    [adc.SchDoc, bom-shield_io.xlsx, connectors.SchDoc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]
2019-11-08 shield_io: chose filter values.
    [adc.SchDoc, shield_io.PrjPcb]
2019-11-08 shield can: use display pcab tst070 model. Remove old display supports.
    [can.SchDoc, display_7.SLDPRT, eva01_connectors.SchDoc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]
2019-11-08 shield can: generate output files.
    [shield_can-display.GBL, shield_can-display.GBO, shield_can-display.GBP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]
2019-11-11 shield 4.3: fix scheme for new display and pcap.
    [display.SchDoc, eva01_connectors.SchDoc, lcd.SchDoc]
2019-11-11 shield 4.3: Complete routing.
    [display.SchDoc, eva01_connectors.SchDoc, shield_display_4.3.PrjPcb]
2019-11-11 shield can: change data connector.
    [can.SchDoc, eva01_connectors.SchDoc, lcd.SchDoc]
2019-11-12 shield can: fix display connector and start to fix pcb.
    [display.SchDoc, lcd.SchDoc]
2019-11-14 Complete routing fixing.
    [can.SchDoc, eva01_connectors.SchDoc, lcd.SchDoc]
2019-11-23 display 4.3 shield: generate output files.
    [bom-shield_display_4.3.xlsx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]
2019-11-23 shield can: add more info to pcb note layere.
    [shield_can-display.PrjPcb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]
2019-11-23 shield display 4.3: add more info to pcb note layer.
    [shield_display_4.3.PrjPcb]
2020-02-07 Fix flat cable position. Arrange board to met met the display flat cable dimenisons.
    [display.SchDoc]
2020-02-12 shield 4.3: fix display connectors position. Regenerate output file. Release pcb ver.E
    [bom-shield_display_4.3.xlsx, display.SchDoc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]
2020-02-12 shield can: fix display connector position. Generate ouput files. Release pcb ver.D
    [bom-shield_can-display.xlsx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]
